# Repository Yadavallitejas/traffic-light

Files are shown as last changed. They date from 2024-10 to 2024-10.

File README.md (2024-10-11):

###Documentation of the Traffic Light system

This documentation provides a detailed explanation of each section of the traffic light project, utilizing components like the **ATmega328P microcontroller**, **7-segment displays**, **CD4511BE driver IC**, **power supply circuitry**, **RGB LED**, and other components. Below, we’ll break down each part of the circuit, their purpose, and how they work together to achieve the goal of controlling a traffic light system.

---

### **1. Power Supply Section**

#### Components:
- **7805 Voltage Regulator (U3)**
- **Diodes (D1)**
- **Capacitors (C1, C2, C3, C4, C5)**

#### Explanation:
- **7805 Voltage Regulator** is used to step down the input voltage (typically from a 9V or 12V source) to a stable 5V for powering the circuit.
- **D1 (1N4007)**: Protects the circuit from reverse polarity in case of incorrect power connections.
- **Capacitors (C1: 100μF, C2: 100μF, C3: 0.1μF, C4: 0.1μF)**: These are filtering capacitors used to smooth out any voltage ripples at the input and output of the regulator, ensuring stable 5V output.
- **LED**: A power indicator LED is connected with a current-limiting resistor to visually indicate when the circuit is powered.

---

### **2. ATmega328P Microcontroller (U1)**

#### Purpose:
The **ATmega328P** is the central controller of the traffic light system. It receives input signals, processes them, and controls the outputs such as the 7-segment display, RGB LED, and any other external components.

#### Key Connections:
- **Power Supply**: VCC and GND pins are connected to the 5V and ground lines, respectively.
- **Crystal Oscillator (XT1)**: A 16 MHz crystal oscillator is connected to pins XTAL1 and XTAL2 with two 22pF capacitors for timing purposes.
- **RESET Pin**: A pull-up resistor (R8, 10kΩ) ensures that the ATmega328P does not reset unintentionally.
  
#### Input/Output Pins:
- **RGB LED Control**: The ATmega328P controls the RGB LED by sending signals to the corresponding R, G, B lines (pins PB0, PB1, PB2).
- **7-Segment Control**: The microcontroller sends BCD (Binary-Coded Decimal) values to the CD4511BE driver to control the 7-segment displays.

#### Programming & Debugging:
- **ISP Header**: A 6-pin header is provided for In-System Programming (ISP) of the ATmega328P. This allows for easy programming and debugging without removing the microcontroller from the circuit. It connects to the MISO, MOSI, SCK, and RESET pins.

---

### **3. CD4511BE - BCD to 7-Segment Driver (U2)**

#### Purpose:
The **CD4511BE** is a BCD (Binary Coded Decimal) to 7-segment display decoder/driver. It takes BCD input from the microcontroller and converts it into the appropriate signals to drive the segments of a common cathode 7-segment display.

#### Key Connections:
- **BCD Input Pins (A, B, C, D)**: These are connected to the output pins of the ATmega328P to receive the BCD signals.
- **Segment Output Pins (a, b, c, d, e, f, g)**: These pins are connected to the corresponding segments of the 7-segment display.
- **Common Cathode Pin**: Connected to ground, this pin allows the control of all the segments through the CD4511BE.
- **LE (Latch Enable)**: Used to control when the output is updated.
- **Outputs**: Controls the SSD (7-segment display) to display numbers (0–9) as part of the traffic light timer.

---

### **4. 7-Segment Displays (SSD1 and SSD2)**

#### Purpose:
The **7-segment displays** are used to display the countdown or time remaining for each traffic light state. This helps visualize the time before the light changes from green to red or vice versa.

#### Key Connections:
- **Cathodes**: The common cathode of the display is connected to ground.
- **Segments**: Each segment (a, b, c, d, e, f, g) is connected to the outputs of the CD4511BE decoder, which controls the display based on the BCD inputs from the ATmega328P.

---

### **5. RGB LED (Q3)**

#### Purpose:
The **RGB LED** is used to represent the traffic lights with red, green, and blue color options. By controlling the intensity of the different colors, the system can simulate the standard traffic light colors: Red (Stop), Green (Go), and Yellow (Caution).

#### Key Connections:
- **R, G, B Lines**: Each color channel (Red, Green, and Blue) is connected to the ATmega328P via current-limiting resistors (R31, R32, R33).
- **Control**: The microcontroller can control the brightness of each color using PWM (Pulse Width Modulation) to adjust the duty cycle, creating different shades and intensities.

---

### **6. Motor Drivers (L293D - not explicitly shown)**

If motor control is required for automated movements (e.g., for controlling barriers), the **L293D H-bridge motor driver** can be integrated into the design. It would control the direction and speed of DC motors by receiving signals from the ATmega328P. The motor driver would likely be powered from the same 5V rail or a separate higher voltage line for motors.

---

### **7. Power LED**

A simple power indicator LED connected in series with a current-limiting resistor, connected to the 5V line, provides a visual indication that the circuit is powered on.

---

### **8. Mounting Holes**

Several mounting holes (marked **MOUNTHOLE2.8**) are included to mechanically secure the PCB to an enclosure or surface, ensuring the board stays fixed during operation.

---

### **Software and Programming**

To operate the traffic light system, a program will need to be loaded onto the ATmega328P microcontroller. Here is a basic outline of the software logic:

#### **Traffic Light Control Algorithm**:
1. **Initialization**: Setup pin modes for the RGB LED, 7-segment display outputs, and the potentiometer input.
2. **Main Loop**:
   - Read the potentiometer value to determine the duration of each traffic light state.
   - Set the RGB LED to **Red** and start the timer countdown, displaying the time on the 7-segment displays.
   - After the timer expires, switch the RGB LED to **Green** and update the 7-segment displays accordingly.
   - Optionally, use **Yellow** as a transition between Red and Green.

### **Conclusion**

This traffic light system is based on a microcontroller (ATmega328P) and uses visual indicators (RGB LED and 7-segment displays) to simulate traffic signals. The circuit integrates standard components like the **CD4511BE** decoder for BCD-to-7-segment control, a regulated **5V power supply** and a robust power circuit, this project is a scalable and educational model of a real-world traffic light system.

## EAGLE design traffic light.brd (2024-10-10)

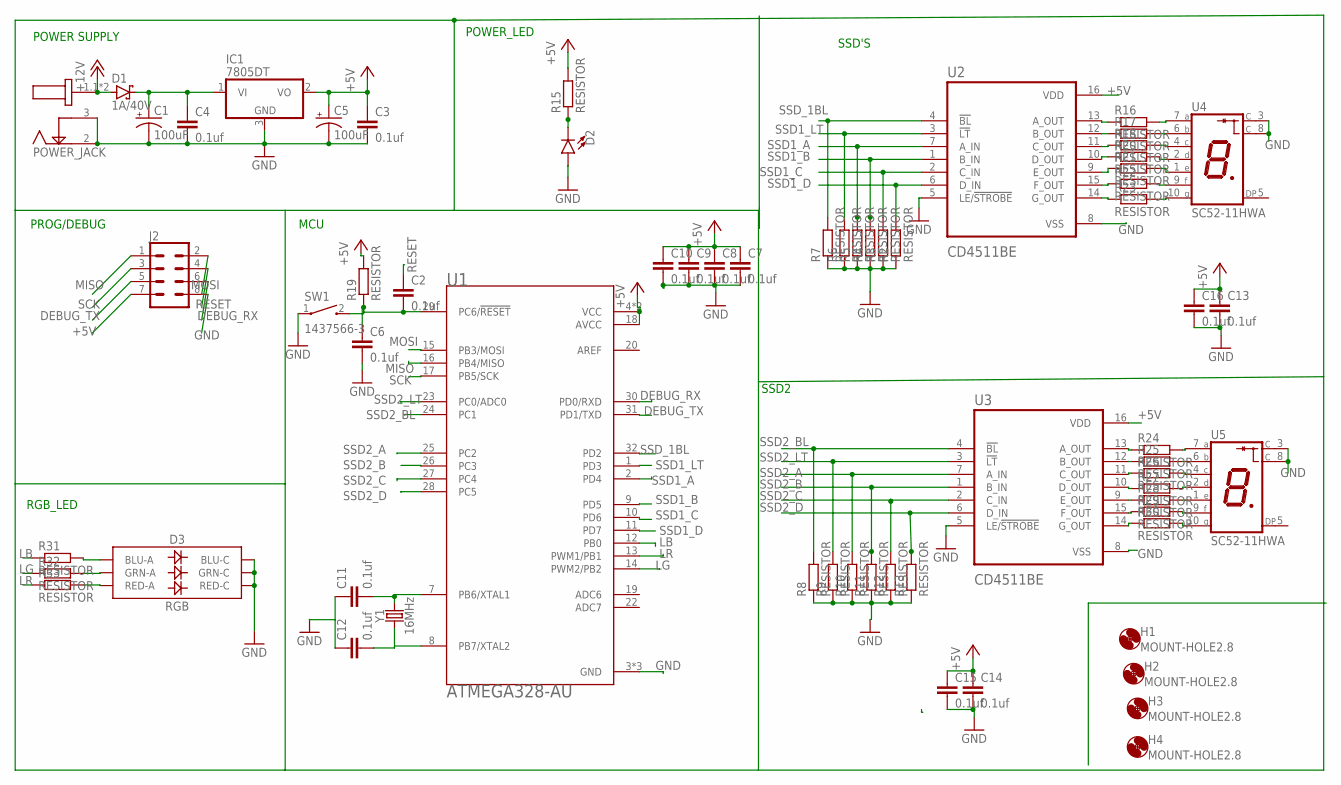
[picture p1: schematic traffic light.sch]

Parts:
C1, C5: 100uF; PANASONIC_D
C2, C4, C6, C11, C12: 0.1uf; C2.5-2
C3, C7, C8, C9, C10, C13, C14, C15, C16: 0.1uf; C2.5-3
D1: 1A/40V; C4111-15
D2: LED0603; LED-0603
D3: RGB; PLCC-6-LED
H1, H2, H3, H4: MOUNT-HOLE2.8; 2,8
IC1: 7805DT; TO252
J2: CONN_04X2; 2X4
POWER_JACK: DCJ200-05-A-XX-X_REVA; GCT_DCJ200-05-A-XX-X_REVA
R2, R3, R4, R5, R6, R7, R8, R9, R10, R11, R12, R13, R15, R16, R17, R18, R19, R20, R21, R22, R23, R24, R25, R26, R27, R28, R29, R30, R31, R32, R33: RESISTOR; R0603
SW1: 1437566-3; SW_1437566-3
U1: ATMEGA328-AU; QFP80P900X900X120-32N
U2, U3: CD4511BE; DIP794W45P254L1969H508Q16
U4, U5: SC52-11HWA; LED_SC52-11HWA
Y1: 16MHz; HC49US

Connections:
+5V: C3.1, C5.+, C7.1, C8.1, C9.1, C10.1, C13.1, C14.1, C15.1, C16.1, IC1.2 (VO), J2.7, R15.2, R19.2, U1.4 (VCC), U1.6 (VCC), U1.18 (AVCC), U2.16 (VDD), U3.16 (VDD)
+12V: D1.A, POWER_JACK.1.1 (1), POWER_JACK.1.2 (1)
DEBUG_RX: J2.6, U1.30 (PD0/RXD)
DEBUG_TX: J2.5, U1.31 (PD1/TXD)
GND: C1.-, C3.2, C4.2, C5.-, C6.2, C7.2, C8.2, C9.2, C10.2, C13.2, C14.2, C15.2, C16.2, D2.A, D3.CB (BLU-C), D3.CG (GRN-C), D3.CR (RED-C), IC1.3 (GND), J2.8, POWER_JACK.2, POWER_JACK.3, R2.1, R3.1, R4.1, R5.1, R6.1, R7.1, R8.1, R9.1, R10.1, R11.1, R12.1, R13.1, SW1.1, U1.3 (GND), U1.5 (GND), U1.21 (GND), U2.5 (LE/!STROBE), U2.8 (VSS), U3.5 (LE/!STROBE), U3.8 (VSS), U4.3 (C), U4.8 (C), U5.3 (C), U5.8 (C)
LB: R31.1, U1.12 (PB0)
LG: R32.1, U1.14 (PWM2/PB2)
LR: R33.1, U1.13 (PWM1/PB1)
MISO: J2.1, U1.16 (PB4/MISO)
MOSI: J2.2, U1.15 (PB3/MOSI)
unnamed: C1.+, C4.1, D1.C, IC1.1 (VI)
unnamed: D3.AB (BLU-A), R31.2
unnamed: D3.AG (GRN-A), R32.2
unnamed: D2.C, R15.1
unnamed: R16.1, U2.13 (A_OUT)
unnamed: R16.2, U4.7 (A)
unnamed: R17.2, U4.6 (B)
unnamed: R17.1, U2.12 (B_OUT)
unnamed: R18.1, U2.11 (C_OUT)
unnamed: R20.1, U2.10 (D_OUT)
unnamed: R21.1, U2.9 (E_OUT)
unnamed: R22.1, U2.15 (F_OUT)
unnamed: R24.1, U3.13 (A_OUT)
unnamed: R24.2, U5.7 (A)
unnamed: R25.1, U3.12 (B_OUT)
unnamed: R26.1, U3.11 (C_OUT)
unnamed: R27.1, U3.10 (D_OUT)
unnamed: R28.1, U3.9 (E_OUT)
unnamed: R29.1, U3.15 (F_OUT)
unnamed: C2.2, C6.1, R19.1, SW1.2, U1.29 (PC6/!RESET)
unnamed: C11.2, U1.7 (PB6/XTAL1), Y1.2
unnamed: C12.2, U1.8 (PB7/XTAL2), Y1.1
unnamed: C11.1, C12.1
unnamed: R23.1, U2.14 (G_OUT)
unnamed: R18.2, U4.4 (C)
unnamed: R20.2, U4.2 (D)
unnamed: R21.2, U4.1 (E)
unnamed: R22.2, U4.9 (F)
unnamed: R23.2, U4.10 (G)
unnamed: R30.1, U3.14 (G_OUT)
unnamed: R30.2, U5.10 (G)
unnamed: R29.2, U5.9 (F)
unnamed: R25.2, U5.6 (B)
unnamed: R26.2, U5.4 (C)
unnamed: R27.2, U5.2 (D)
unnamed: R28.2, U5.1 (E)
unnamed: D3.AR (RED-A), R33.2
RESET: C2.1, J2.4
SCK: J2.3, U1.17 (PB5/SCK)
SSD1_A: R5.2, U1.2 (PD4), U2.7 (A_IN)
SSD1_B: R4.2, U1.9 (PD5), U2.1 (B_IN)
SSD1_C: R3.2, U1.10 (PD6), U2.2 (C_IN)
SSD1_D: R2.2, U1.11 (PD7), U2.6 (D_IN)
SSD1_LT: R6.2, U1.1 (PD3), U2.3 (!LT)
SSD2_A: R10.2, U1.25 (PC2), U3.7 (A_IN)
SSD2_B: R11.2, U1.26 (PC3), U3.1 (B_IN)
SSD2_BL: R8.2, U1.24 (PC1), U3.4 (!BL)
SSD2_C: R12.2, U1.27 (PC4), U3.2 (C_IN)
SSD2_D: R13.2, U1.28 (PC5), U3.6 (D_IN)
SSD2_LT: R9.2, U1.23 (PC0/ADC0), U3.3 (!LT)
SSD_1BL: R7.2, U1.32 (PD2), U2.4 (!BL)

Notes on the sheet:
POWER SUPPLY
RGB_LED
SSD'S
PROG/DEBUG
POWER_LED
SSD2
MCU

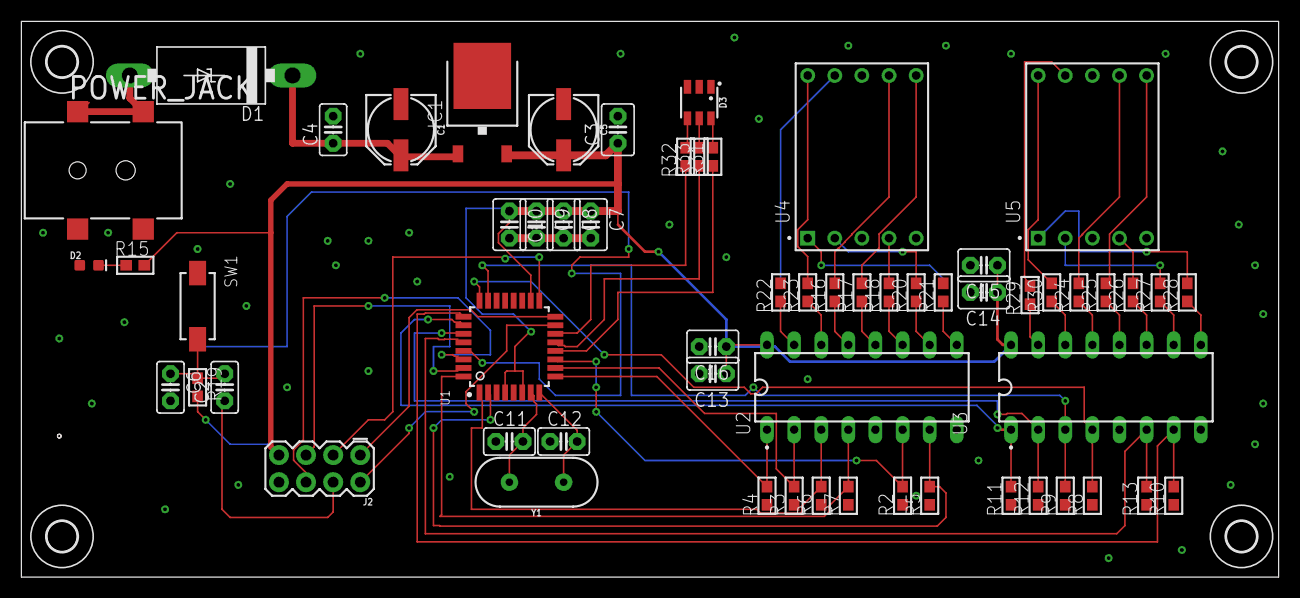
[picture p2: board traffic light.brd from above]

Board: 2 copper layers, 117.8 x 52.1 mm, 64 parts (0 on the bottom side), 61 nets.

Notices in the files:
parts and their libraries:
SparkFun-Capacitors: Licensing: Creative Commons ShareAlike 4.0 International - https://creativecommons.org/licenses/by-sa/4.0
